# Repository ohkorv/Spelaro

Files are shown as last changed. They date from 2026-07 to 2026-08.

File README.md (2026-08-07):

<h1 align="center">

<br> Spelarö <br>

<h4 align="center">
A standalone audio player and optical transmitter powered by the ESP32-S3. Play FLAC and MP3 files from a micro SD card, navigate your library using the 2.8-inch screen and 5-way switch, and output clean digital audio via TOSLINK.
</h4>





front

# About the project

Spelarö is a custom hardware project that lets you play flac and mp3 files directly from a micro SD card. It sends the data optically via a toslink transmitter with a toslink cable. There was no product like this, so i decided to make my own for me and my dad.

## How It Works

* **Storage:** Music files are stored on a standard micro SD card. The ESP32-S3 reads the files directly from the card. It then sends it via toslink.
* **Interface:** You use a 2.8-inch TFT display to see your library and a 5-way joystick switch to navigate through your libary of songs. 
* **Audio Output:** The ESP32-S3 processes the audio data and sends it out through a toslink transmitter. This results in perfect audio for audiophiles like me and my dad. 
* **Status LED:** An onboard NeoPixel (WS2812B) provides visual feedback for power status and can be programmed to follow the song's rhythm or anything you want.

## Features

* **ESP32-S3-NANO** microcontroller
* **1x 2.8" TFT Display** 
* **1x 5-way tactile joystick switch** 
* **1x 1-way tactile switch** 
* **1x Micro SD Card Reader** 
* **1x Neopixel WS2812B** 
* **1x Optical Toslink Transmitter (OTJ-5)** 

# Schematic


# PCB



# Bill Of Materials

| Designator | Footprint | Qty | Value | Link | Price (USD) |
| :--- | :--- | :---: | :--- | :--- | :---: |
| A1 | `MODULE_NANO-ESP32-ENTRY` | 1 | Arduino_Nano_ESP32 | [Electrokit](https://www.electrokit.com/utvecklingskort-esp32-s3-nano-kompatibelt) | $16.72 |
| C1 | `1206` | 1 | 100nF | [Electrokit](https://www.electrokit.com/kondensator-1206-x7r-100nf-10) | $1.05 |
| J1 | `PinHeader_1x14_P2.54mm_Vertical` | 1 | Conn_01x14_Pin | [Amazon](https://www.amazon.se/gp/product/B09Z29CGY1/ref=ox_sc_act_image_1?smid=A3LA1TDA4Q3SUA&psc=1) | $13.67 |
| LED1 | `WS2812B` | 1 | WS2812B | [Electrokit](https://www.electrokit.com/led-smd5050-rgb-adresserbar-sk6812) | $1.31 |
| R1, R2, R3 | `1206` | 3 | 10k | [Electrokit](https://www.electrokit.com/motstand-10kohm-0.25w-smd-1206) | $1.05 |
| S1 | `SW_VS-1213-67-160GF` | 1 | VS-1213-67-160GF | [Electrokit](https://www.electrokit.com/tryckknapp-pcb-12x12x5mm) | $1.35 |
| SW1 | `C145910` | 1 | K1-1506SN-01 | [Electrokit](https://www.electrokit.com/joystick-navigationsknapp-5-vags-smd-10x10mm-1) | $1.95 |
| TF1 | `TF-SMD_TF-012` | 1 | TF-CARD H1.8 SY | [Electrokit](https://www.electrokit.com/kontakt-microsd) | $1.37 |
| U3 | `toslink` | 1 | OTJ-5 | [Electrokit](https://www.electrokit.com/toslink-optisk-sandare-pcb) | $2.94 |
| PCB | - | 5 | - | [JLCPCB](https://jlcpcb.com/) | $2.10 |
| **Shipping** | - | - | - | - | $33.01 |
| **Total** | - | - | - | - | **$76.52** |

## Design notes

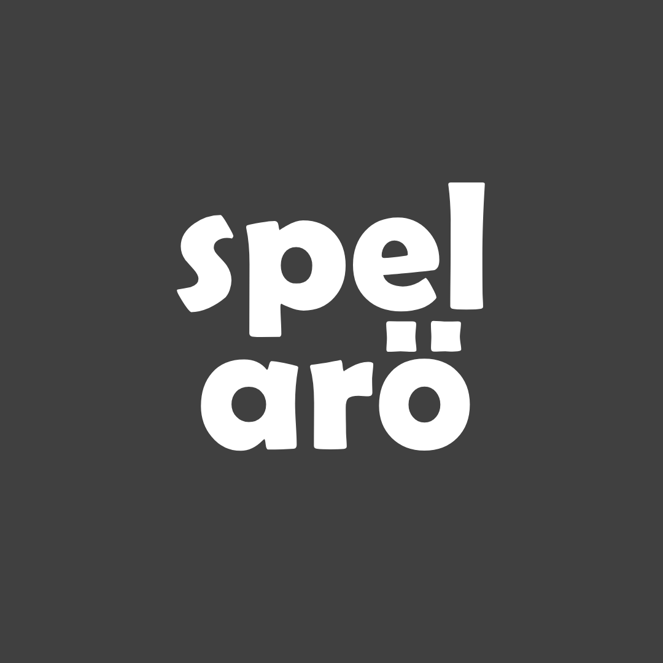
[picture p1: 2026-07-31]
Images/photo.png

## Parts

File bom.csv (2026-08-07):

Designator | Footprint | Quantity | Value | Link
A1 | MODULE_NANO-ESP32-ENTRY | 1 | Arduino_Nano_ESP32 | https://www.electrokit.com/utvecklingskort-esp32-s3-nano-kompatibelt
C1 | 1206 | 1 | 100nF | https://www.electrokit.com/kondensator-1206-x7r-100nf-10
J1 | PinHeader_1x14_P2.54mm_Vertical | 1 | Conn_01x14_Pin | https://www.amazon.se/gp/product/B09Z29CGY1/ref=ox_sc_act_image_1?smid=A3LA1TDA4Q3SUA&psc=1
LED1 | WS2812B | 1 | WS2812B | https://www.electrokit.com/led-smd5050-rgb-adresserbar-sk6812
R1, R2, R3 | 1206 | 3 | 10k | https://www.electrokit.com/motstand-10kohm-0.25w-smd-1206
S1 | SW_VS-1213-67-160GF | 1 | VS-1213-67-160GF | https://www.electrokit.com/tryckknapp-pcb-12x12x5mm
SW1 | C145910 | 1 | K1-1506SN-01 | https://www.electrokit.com/joystick-navigationsknapp-5-vags-smd-10x10mm-1
TF1 | TF-SMD_TF-012 | 1 | TF-CARD H1.8 SY | https://www.electrokit.com/kontakt-microsd
U3 | toslink | 1 | OTJ-5 | https://www.electrokit.com/toslink-optisk-sandare-pcb
PCB | - | 5 | PCB | https://jlcpcb.com/
Shipping | - | 1 | Shipping ($33.01)
Total | - |  | - | $76.52

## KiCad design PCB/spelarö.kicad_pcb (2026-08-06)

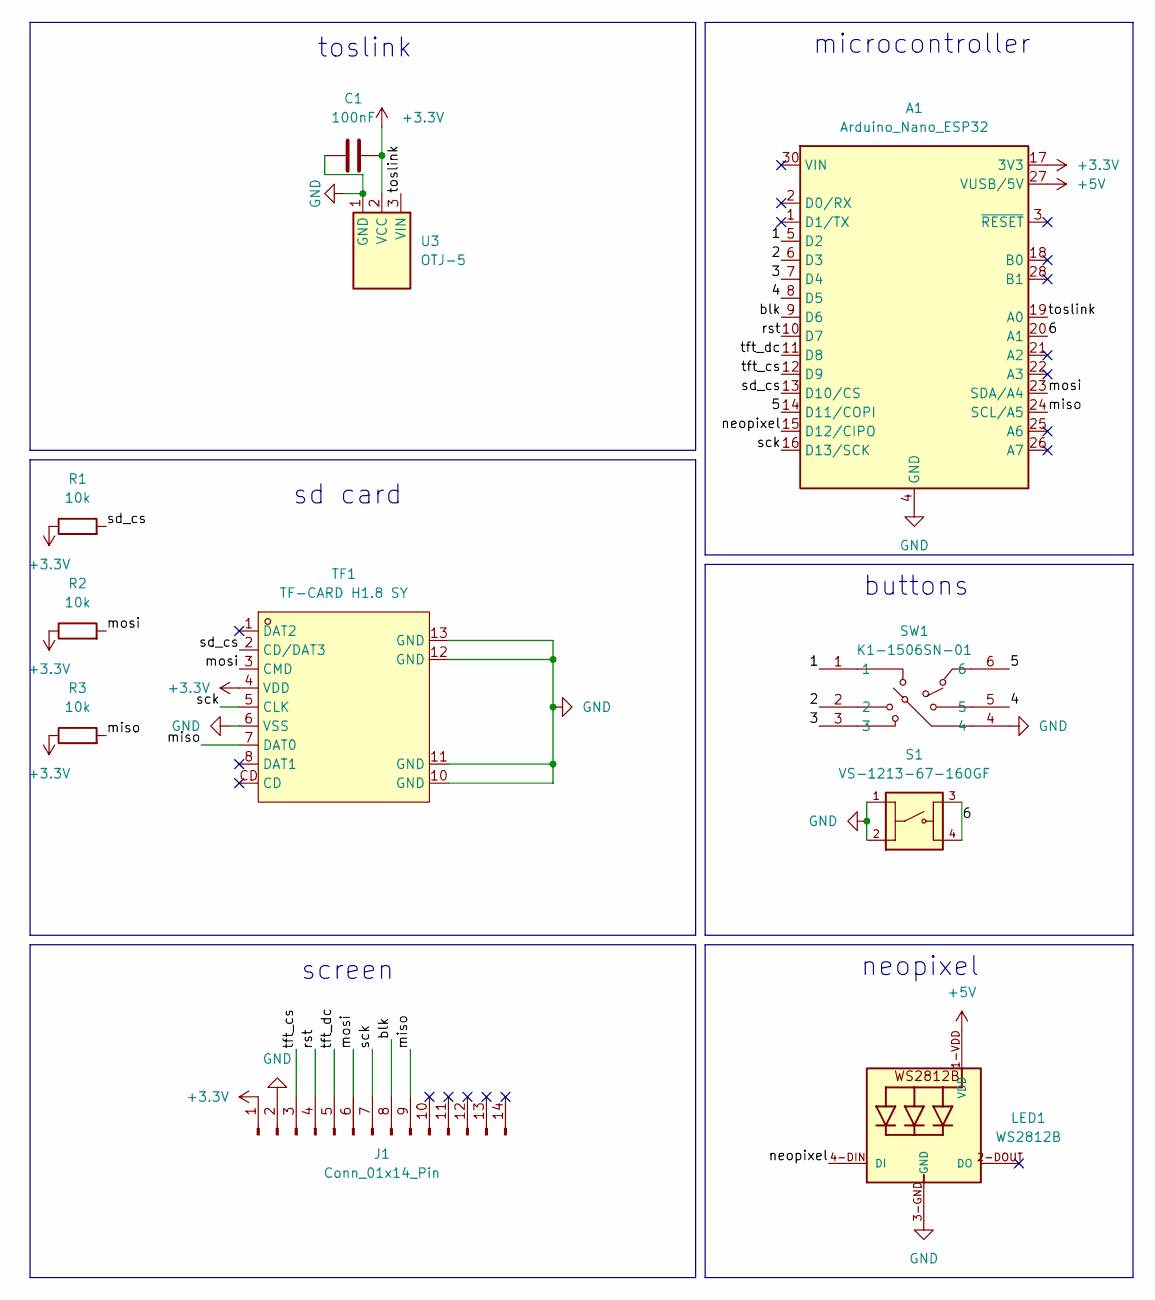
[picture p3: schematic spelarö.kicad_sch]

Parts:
A1: Arduino_Nano_ESP32; MODULE_NANO-ESP32-ENTRY
C1: 100nF; C_1206_3216Metric
J1: Conn_01x14_Pin; PinHeader_1x14_P2.54mm_Vertical
LED1: WS2812B
R1, R2, R3: 10k; R_1206_3216Metric
S1: VS-1213-67-160GF; SW_VS-1213-67-160GF; PARTREV N/A
SW1: K1-1506SN-01; C145910; MPN K1-1506SN-01; LCSC Part C145910
TF1: TF-CARD H1.8 SY; TF-SMD_TF-012; MPN TF-CARD H1.8 SY; LCSC Part C7529391
U3: OTJ-5; toslink

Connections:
+3.3V: A1.17 (3V3), C1.1, J1.1, R1.1, R2.1, R3.1, TF1.4 (VDD), U3.2 (VCC)
+5V: A1.27 (VUSB/5V), LED1.1-VDD (VDD)
/1: A1.5 (D2), SW1.1
/2: A1.6 (D3), SW1.2
/3: A1.7 (D4), SW1.3
/4: A1.8 (D5), SW1.5
/5: A1.14 (D11/COPI), SW1.6
/6: A1.20 (A1), S1.3, S1.4
/blk: A1.9 (D6), J1.8
/miso: A1.24 (SCL/A5), J1.9, R3.2, TF1.7 (DAT0)
/mosi: A1.23 (SDA/A4), J1.6, R2.2, TF1.3 (CMD)
/neopixel: A1.15 (D12/CIPO), LED1.4-DIN (DI)
/rst: A1.10 (D7), J1.4
/sck: A1.16 (D13/SCK), J1.7, TF1.5 (CLK)
/sd_cs: A1.13 (D10/CS), R1.2, TF1.2 (CD/DAT3)
/tft_cs: A1.12 (D9), J1.3
/tft_dc: A1.11 (D8), J1.5
/toslink: A1.19 (A0), U3.3 (VIN)
GND: A1.4 (GND), A1.29 (GND), C1.2, J1.2, LED1.3-GND (GND), S1.1, S1.2, SW1.4, TF1.6 (VSS), TF1.10 (GND), TF1.11 (GND), TF1.12 (GND), TF1.13 (GND), U3.1 (GND)

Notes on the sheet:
buttons
sd card
neopixel
toslink
microcontroller
screen

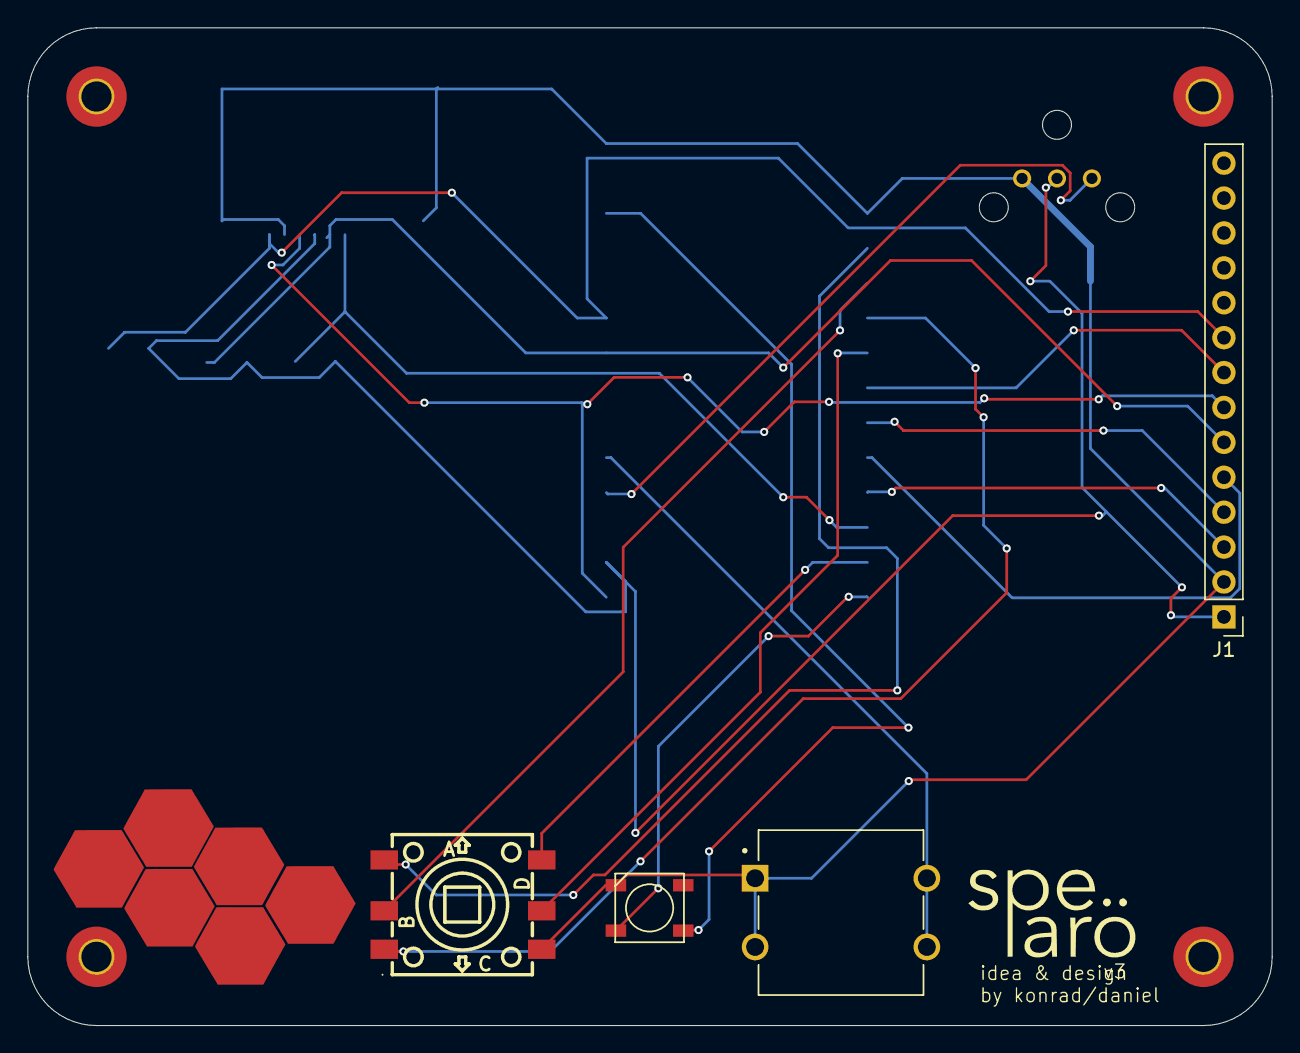
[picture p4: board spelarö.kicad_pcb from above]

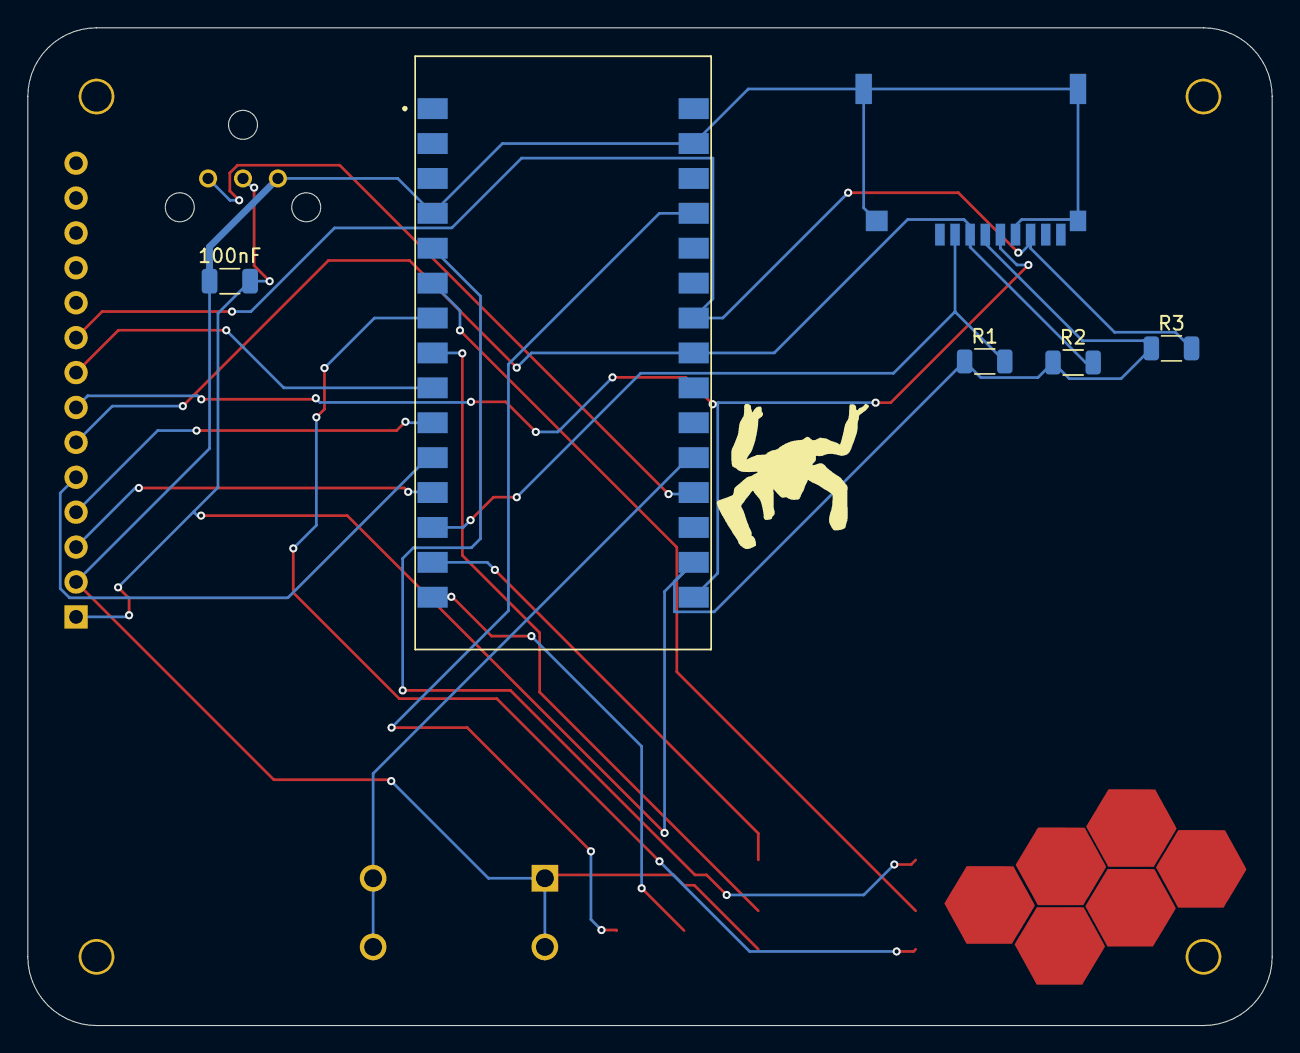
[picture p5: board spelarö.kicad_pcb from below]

Board: 2 copper layers, 90.6 x 72.6 mm, 11 parts (7 on the bottom side), 19 nets.

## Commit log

2026-07-22 finished the pcb
    [bom.csv, designators.csv, positions.csv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]
2026-07-31 fixed the pcb
    [bom.csv, designators.csv, positions.csv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]
2026-07-31 fixed folder name
    [bom.csv, designators.csv, positions.csv]
2026-07-31 started rendering in blender
    [bom.csv, designators.csv, positions.csv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]
2026-07-31 Update README with project features and schematic
    Added project features and schematic images to README.
2026-08-01 Add PCB section with images to README
    Added PCB images to the README.
2026-08-01 fixed bom
    [bom.csv, designators.csv, positions.csv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]
2026-08-01 added gerber
2026-08-06 Add Bill of Materials to README
    Added a Bill of Materials section with components and pricing.
2026-08-06 Clean up BOM by removing prices and quantities
    Removed price and quantity details from the BOM.
    [bom.csv]
2026-08-07 Clarify audio output method in README
    Updated the README to clarify that the ESP32-S3 sends audio via toslink after reading from the micro SD card.

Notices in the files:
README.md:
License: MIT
